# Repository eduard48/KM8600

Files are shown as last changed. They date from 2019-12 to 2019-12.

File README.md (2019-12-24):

# Конфигурируемый контроллер серии КМ тип КМ8600 

>КМ8600 – контроллер для жестких условий эксплуатации

>>Выпускается [здесь](http://www.sem-act.ru)

>>Тип модуля: КM01-8600.M

>>Версия: 0330

В папке Firmware проект для AtmelStudio v.6.2

В папке Hardware две платы (контроллер и модуль индикации) для Altium Desinger 2017.

В папке Docs описания и документы.

				>Краткие характеристики

>>Дискретных входов - 8

>>Дискретных выходов - 6 (реле с NO контактами)

>>Номинальное напряжение питания - 24 VDC

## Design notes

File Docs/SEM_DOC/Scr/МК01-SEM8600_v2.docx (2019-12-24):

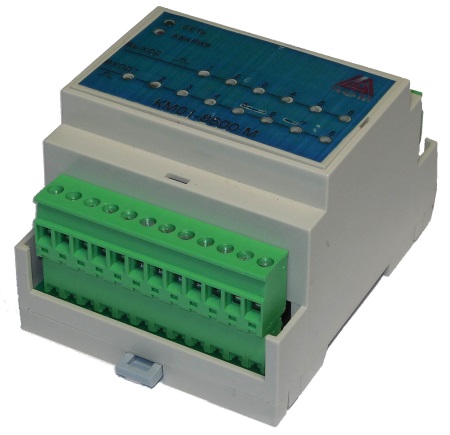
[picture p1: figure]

КМ – серия контроллеров для жестких условий эксплуатации Модуль: КM01-8600.M

Основные технические характеристики:

Напряжение питания 24VDC +/-20%

Рабочая температура -40…+70С

Потребляемая мощность 2.4Вт

Защита цепей 6 видов

Программа конфигуратор, единая на всю серию модулей КМ, поставляется бесплатно

Кол-во дискретных входных сигналов 8

Кол-во дискретных выходных сигналов 6

Гальванически развязанный интерфейс RS485

Поддержка протокола ModBus RTU

Габаритные размеры 85х71х57мм

Установка на DIN-рейку

Гальванически развязанные входы могут быть сконфигурированы как счетные (8 входов).

Выходы с открытым коллектором могут быть сконфигурированы как выходы ШИМ (2 выхода).

Релейные выходы могут коммутировать ток до 5 Ампер.

Защита по питанию и питанию входов - само-восстанавливающимися предохранителями.

Поставляются совместно с библиотекой функций для программирования на языке С.

Используется совместно со Scada системами такими как: Vijeo Citect, Citect, Master Scada и т.д.

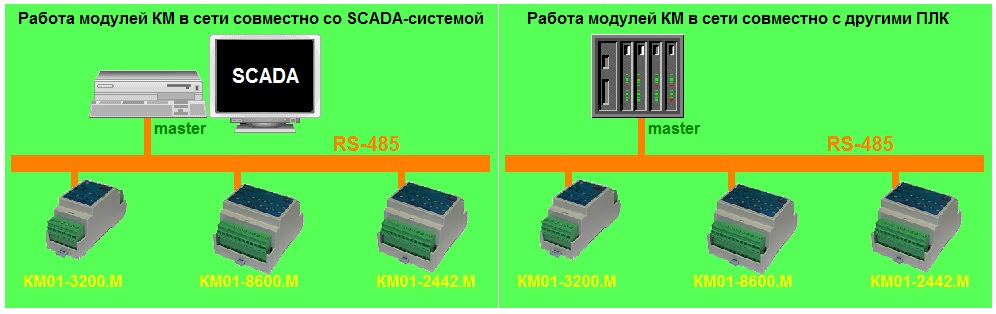
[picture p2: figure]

Более подробные характеристики смотреть в инструкции по эксплуатации модуля КМ01-8600.М

Настройки конфигурации смотреть в инструкции пользователя программой “Конфигуратор КМ”

Программирование смотреть в “Инструкция по программированию контроллера КМ01-8600.М”

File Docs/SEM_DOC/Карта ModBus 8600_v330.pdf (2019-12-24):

## KM01-8600.M (версия ПО 330)

Регистры Input | (регистры только для чтения)
ModBus addr | Имя регистра | Описание | Примечание | Тип памяти
30001 | MB_Ireg[0] | Слово жизни контроллера | Постоянное изменение - контроллер работает | RAM
30002 | MB_Ireg[1].0 | Состояние входа DI1
30002 | MB_Ireg[1].1 | Состояние входа DI2
30002 | MB_Ireg[1].2 | Состояние входа DI3
30002 | MB_Ireg[1].3 | Состояние входа DI4
30002 | MB_Ireg[1].4 | Состояние входа DI5
30002 | MB_Ireg[1].5 | Состояние входа DI6
30002 | MB_Ireg[1].6 | Состояние входа DI7
30002 | MB_Ireg[1].7 | Состояние входа DI8
30002 | MB_Ireg[1].8 | Состояние входа контроля напряжения UDI
30002 | MB_Ireg[1].9 | Резерв
30002 | MB_Ireg[1].10 | Резерв
30002 | MB_Ireg[1].11 | Резерв
30002 | MB_Ireg[1].12 | Резерв
30002 | MB_Ireg[1].13 | Резерв
30002 | MB_Ireg[1].14 | Резерв
30002 | MB_Ireg[1].15 | Резерв
30002 | MB_Ireg[1] | Состояние дискретных входов DI | 8 входов + 1 контроль напряжения питания входов | RAM
30003 | MB_Ireg[2].0 | Состояние выхода DO1
30003 | MB_Ireg[2].1 | Состояние выхода DO2
30003 | MB_Ireg[2].2 | Состояние выхода DO3
30003 | MB_Ireg[2].3 | Состояние выхода DO4
30003 | MB_Ireg[2].4 | Состояние выхода DO5
30003 | MB_Ireg[2].5 | Состояние выхода DO6
30003 | MB_Ireg[2].6 | Резерв
30003 | MB_Ireg[2].7 | Резерв
30003 | MB_Ireg[2].8 | Резерв
30003 | MB_Ireg[2].9 | Резерв
30003 | MB_Ireg[2].10 | Резерв
30003 | MB_Ireg[2].11 | Резерв
30003 | MB_Ireg[2].12 | Резерв
30003 | MB_Ireg[2].13 | Резерв
30003 | MB_Ireg[2].14 | Резерв
30003 | MB_Ireg[2].15 | Резерв
30003 | MB_Ireg[2] | Состояние дискретных выходов DO | 6 выходов (4 реле и 2 с ОК) | RAM
30004 | MB_Ireg[3] | Резерв
30005 | MB_Ireg[4] | Резерв
30006 | MB_Ireg[5] | Резерв
30007 | MB_Ireg[6] | Резерв
30008 | MB_Ireg[7] | Резерв
30009 | MB_Ireg[8] | Резерв
30010 | MB_Ireg[9] | значение дискретного выхода №5 | Если задана работа в качестве ШИМ, дипазон 0…255
30011 | MB_Ireg[10] | значение дискретного выхода №6 | Если задана работа в качестве ШИМ, дипазон 0…255
30004…30011 | MB_Ireg[3]…[10] | Значения аналоговых входов/выходов | | RAM
30012 | MB_Ireg[11] | Старшее число текущего значения для счетного входа №1
30013 | MB_Ireg[12] | Младшее число текущего значения для счетного входа №1
30014 | MB_Ireg[13] | Старшее число текущего значения для счетного входа №2
30015 | MB_Ireg[14] | Младшее число текущего значения для счетного входа №2
30016 | MB_Ireg[15] | Старшее число текущего значения для счетного входа №3
30017 | MB_Ireg[16] | Младшее число текущего значения для счетного входа №3
30018 | MB_Ireg[17] | Старшее число текущего значения для счетного входа №4
30019 | MB_Ireg[18] | Младшее число текущего значения для счетного входа №4
30020 | MB_Ireg[19] | Старшее число текущего значения для счетного входа №5
30021 | MB_Ireg[20] | Младшее число текущего значения для счетного входа №5
30022 | MB_Ireg[21] | Старшее число текущего значения для счетного входа №6
30023 | MB_Ireg[22] | Младшее число текущего значения для счетного входа №6
30024 | MB_Ireg[23] | Старшее число текущего значения для счетного входа №7
30025 | MB_Ireg[24] | Младшее число текущего значения для счетного входа №7
30026 | MB_Ireg[25] | Старшее число текущего значения для счетного входа №8
30027 | MB_Ireg[26] | Младшее число текущего значения для счетного входа №8
30012…30027 | MB_Ireg[11]…[26] | Значения счетных входов | | RAM
30028 | MB_Ireg[27].0 | Состояние инд. дискретного Выхода №6 | зеленый светодиод №6
30028 | MB_Ireg[27].1 | Состояние инд. дискретного Выхода №5 | зеленый светодиод №5
30028 | MB_Ireg[27].2 | Состояние инд. дискретного Выхода №4 | зеленый светодиод №4
30028 | MB_Ireg[27].3 | Состояние инд. дискретного Выхода №3 | зеленый светодиод №3
30028 | MB_Ireg[27].4 | Состояние инд. дискретного Выхода №2 | зеленый светодиод №2
30028 | MB_Ireg[27].5 | Состояние инд. дискретного Выхода №1 | зеленый светодиод №1
30028 | MB_Ireg[27].6 | Состояние инд. "Неисправность" | Красный светодиод
30028 | MB_Ireg[27].7 | резерв
30028 | MB_Ireg[27].8 | Состояние инд. дискретного Входа №8 | желтый светодиод №8
30028 | MB_Ireg[27].9 | Состояние инд. дискретного Входа №7 | желтый светодиод №7
30028 | MB_Ireg[27].10 | Состояние инд. дискретного Входа №6 | желтый светодиод №6
30028 | MB_Ireg[27].11 | Состояние инд. дискретного Входа №5 | желтый светодиод №5
30028 | MB_Ireg[27].12 | Состояние инд. дискретного Входа №4 | желтый светодиод №4
30028 | MB_Ireg[27].13 | Состояние инд. дискретного Входа №3 | желтый светодиод №3
30028 | MB_Ireg[27].14 | Состояние инд. дискретного Входа №2 | желтый светодиод №2
30028 | MB_Ireg[27].15 | Состояние инд. дискретного Входа №1 | желтый светодиод №1
30028 | MB_Ireg[27] | Состояние индикации (светодиодов) | Используется для сдвигового регистра индикации | RAM
30029 | MB_Ireg[28] | KM
30030 | MB_Ireg[29] | 01
30031 | MB_Ireg[30] | -8
30032 | MB_Ireg[31] | 60
30033 | MB_Ireg[32] | 0.
30034 | MB_Ireg[33] | M0
30035 | MB_Ireg[34] | резерв
30036 | MB_Ireg[35] | резерв
30029...30036 | MB_Ireg[28]…[35] | Имя модуля в памяти | Пример: KM01-8600.M (длинна макс 16 символов) | RAM
30037 | MB_Ireg[36] | 02 | 02 - версия загрузчика
30038 | MB_Ireg[37] | 03 | 03
30039 | MB_Ireg[38] | 00 | 00
30037...30039 | MB_Ireg[36]…[38] | Номер версии ПО | Пример: 020300 | RAM
30040 | MB_Ireg[39] | 09 | 09 - неделя выпуска
30041 | MB_Ireg[40] | 00
30042 | MB_Ireg[41] | 01
30040…30042 | MB_Ireg[39]…[41] | Серийный номер контроллера | Пример: серийный номер 090001 | RAM
Регистры Hold | (регистры для чтения и записи)

ModBus addr | Имя регистра | Описание | Примечание | Тип памяти
40001 | MB_Hreg[0] | Резерв | Это все
40002 | MB_Hreg[1] | Резерв | для
40003 | MB_Hreg[2] | Резерв | пользовательской программы
40004 | MB_Hreg[3] | Резерв | Если надо!
40005 | MB_Hreg[4] | Резерв
40001…40005 | MB_Hreg[0]…[4] | Резерв | | RAM
40006 | MB_Hreg[5].0 | Управление выходом DO1
40006 | MB_Hreg[5].1 | Управление выходом DO2
40006 | MB_Hreg[5].2 | Управление выходом DO3
40006 | MB_Hreg[5].3 | Управление выходом DO4
40006 | MB_Hreg[5].4 | Управление выходом DO5
40006 | MB_Hreg[5].5 | Управление выходом DO6
40006 | MB_Hreg[5].6 | Резерв
40006 | MB_Hreg[5].7 | Резерв
40006 | MB_Hreg[5].8 | Резерв
40006 | MB_Hreg[5].9 | Резерв
40006 | MB_Hreg[5].10 | Резерв
40006 | MB_Hreg[5].11 | Резерв
40006 | MB_Hreg[5].12 | Резерв
40006 | MB_Hreg[5].13 | Резерв
40006 | MB_Hreg[5].14 | Резерв
40006 | MB_Hreg[5].15 | Резерв
40006 | MB_Hreg[5] | Слово состояния и управления дискретными выходами контроллера | | RAM
40007 | MB_Hreg[6] | резерв
40008 | MB_Hreg[7] | резерв
40009 | MB_Hreg[8] | Управление выходом ШИМ DO5 | Имеет значение только если выход настроен на работу в качестве ШИМ. Изменяется только (0…255)
40010 | MB_Hreg[9] | Управление выходом ШИМ DO6 | Имеет значение только если выход настроен на работу в качестве ШИМ. Изменяется только (0…255)
40007…40010 | MB_Hreg[6]…[9] | Слова управления аналоговыми выходами | | RAM
40011 | MB_Hreg[10] | резерв
40012 | MB_Hreg[11] | резерв
40013 | MB_Hreg[12] | резерв
40014 | MB_Hreg[13] | резерв
40015 | MB_Hreg[14] | резерв
40016 | MB_Hreg[15] | резерв
40017 | MB_Hreg[16] | резерв
40018 | MB_Hreg[17] | резерв
40019 | MB_Hreg[18] | резерв
40020 | MB_Hreg[19] | резерв
40021 | MB_Hreg[20] | резерв
40022 | MB_Hreg[21] | резерв
40023 | MB_Hreg[22] | резерв
40024 | MB_Hreg[23] | резерв
40025 | MB_Hreg[24] | резерв
40026 | MB_Hreg[25] | резерв
40027 | MB_Hreg[26] | резерв
40028 | MB_Hreg[27] | резерв
40029 | MB_Hreg[28] | резерв
40030 | MB_Hreg[29] | резерв
40031 | MB_Hreg[30] | резерв
40032 | MB_Hreg[31] | резерв
40033 | MB_Hreg[32] | резерв
40034 | MB_Hreg[33] | резерв
40011…40034 | MB_Hreg[10]…[33] | Резерв | | RAM
40035 | MB_Hreg[34].0 | Режим ШИМ для выхода №5 (DO5) включен
40035 | MB_Hreg[34].1 | Режим ШИМ для выхода №6 (DO6) включен
40035 | MB_Hreg[34].2 | Резерв
40035 | MB_Hreg[34].3 | Резерв
40035 | MB_Hreg[34].4 | Резерв
40035 | MB_Hreg[34].5 | Резерв
40035 | MB_Hreg[34].6 | Резерв
40035 | MB_Hreg[34].7 | Резерв
40035 | MB_Hreg[34].8…9 | Задание частоты ШИМ для выходов №5, №6 | 00 - 60Гц, 01-120Гц, 10-240Гц, 11-580Гц
40035 | MB_Hreg[34].10 | Резерв
40035 | MB_Hreg[34].11 | Резерв
40035 | MB_Hreg[34].12 | Резерв
40035 | MB_Hreg[34].13 | Резерв
40035 | MB_Hreg[34].14 | Резерв
40035 | MB_Hreg[34] | Параметры ШИМ для выходов с ОК (№5, №6) | Новые параметры работают только перезагрузки. | RAM, EEPROM
40036 | MB_Hreg[35].0 | Вход №1 работает как счетный
40036 | MB_Hreg[35].1 | Вход №2 работает как счетный
40036 | MB_Hreg[35].2 | Вход №3 работает как счетный
40036 | MB_Hreg[35].3 | Вход №4 работает как счетный
40036 | MB_Hreg[35].4 | Вход №5 работает как счетный
40036 | MB_Hreg[35].5 | Вход №6 работает как счетный
40036 | MB_Hreg[35].6 | Вход №7 работает как счетный
40036 | MB_Hreg[35].7 | Вход №8 работает как счетный
40036 | MB_Hreg[35].8
40036 | MB_Hreg[35].9
40036 | MB_Hreg[35].10
40036 | MB_Hreg[35].11
40036 | MB_Hreg[35].12
40036 | MB_Hreg[35].13
40036 | MB_Hreg[35].14
40036 | MB_Hreg[35].15
40036 | MB_Hreg[35] | Режим работы цифровых входов | Новые параметры работают только перезагрузки. | RAM, EEPROM
40037 | MB_Hreg[36] | Число накопителя для счетного входа №1
40038 | MB_Hreg[37] | Число накопителя для счетного входа №2
40039 | MB_Hreg[38] | Число накопителя для счетного входа №3
40040 | MB_Hreg[39] | Число накопителя для счетного входа №4
40041 | MB_Hreg[40] | Число накопителя для счетного входа №5
40042 | MB_Hreg[41] | Число накопителя для счетного входа №6
40043 | MB_Hreg[42] | Число накопителя для счетного входа №7
40044 | MB_Hreg[43] | Число накопителя для счетного входа №8
40045 | MB_Hreg[44] | Старшее число начального значения для счетного входа №1
40046 | MB_Hreg[45] | Младшее число начального значения для счетного входа №1
40047 | MB_Hreg[46] | Старшее число начального значения для счетного входа №2

40048 | MB_Hreg[47] | Младшее число начального значения для счетного входа №2
40049 | MB_Hreg[48] | Старшее число начального значения для счетного входа №3
40050 | MB_Hreg[49] | Младшее число начального значения для счетного входа №3
40051 | MB_Hreg[50] | Старшее число начального значения для счетного входа №4
40052 | MB_Hreg[51] | Младшее число начального значения для счетного входа №4
40053 | MB_Hreg[52] | Старшее число начального значения для счетного входа №5
40054 | MB_Hreg[53] | Младшее число начального значения для счетного входа №5
40055 | MB_Hreg[54] | Старшее число начального значения для счетного входа №6
40056 | MB_Hreg[55] | Младшее число начального значения для счетного входа №6
40057 | MB_Hreg[56] | Старшее число начального значения для счетного входа №7
40058 | MB_Hreg[57] | Младшее число начального значения для счетного входа №7
40059 | MB_Hreg[58] | Старшее число начального значения для счетного входа №8
40060 | MB_Hreg[59] | Младшее число начального значения для счетного входа №8
40061 | MB_Hreg[60] | резерв
40037…40061 | MB_Hreg[36]…[60] | Уставки для счетных входов | Новые параметры работают только перезагрузки. | RAM, EEPROM
40062 | MB_Hreg[61].0…7 | Адрес контроллера в сети ModBus | Сетевой адрес
40062 | MB_Hreg[61].8 | резерв
40062 | MB_Hreg[61].9 | резерв
40062 | MB_Hreg[61].10 | резерв
40062 | MB_Hreg[61].11 | резерв
40062 | MB_Hreg[61].12 | резерв
40062 | MB_Hreg[61].13 | резерв
40062 | MB_Hreg[61].14 | резерв
40062 | MB_Hreg[61].15 | резерв
40062 | MB_Hreg[61] | Параметры сети MODBUS | Новые параметры работают только перезагрузки. | RAM, EEPROM
40063 | MB_Hreg[62].0…7 | Категория скорости в сети | 0x00, 0x01, 0x02, 0x06 - 9600 бит/сек
40063 | | | 0x03 - 1200 бит/сек
40063 | | | 0x04 - 2400 бит/сек
40063 | | | 0x05 - 4800 бит/сек
40063 | | | 0x07 - 19200 бит/сек
40063 | | | 0x08 - 38400 бит/сек
40063 | | | 0x09 - 57600 бит/сек
40063 | | | 0x0A - 115200 бит/сек
40063 | MB_Hreg[62].8…15 | Параметры обмена | default | 0x00 - 8, Even, 1
40063 | | | 0x01 - 8, Even, 2
40063 | | | 0x02 - 8, None, 1
40063 | | | 0x03 - 8, None, 2
40063 | MB_Hreg[62] | Параметры RS - 485 | Новые параметры работают только перезагрузки. | RAM, EEPROM
40064 | MB_Hreg[63].0 | Выполнить перезагрузку | Работает только при записи в этот бит 1. Т.е. по фронту сигнала.
40064 | MB_Hreg[63] | Команды контроллера | Срабатывает при изменении 0 бита на 1 | RAM

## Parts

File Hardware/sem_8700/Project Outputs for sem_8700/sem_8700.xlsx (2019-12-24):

Comment | Designator | Footprint | Quantity
0.1 | C1, C3, C6, C8, C9, C10, C11, C12, C15, C16 | CAPC2113X13N_0805 | 10
470.0x50V | C2 | Cap_pol_13x25 | 1
470 pF | C4 | CAPC2113X13N_0805 | 1
470.0x35V | C5 | Cap_2(10x12.5) | 1
22.0x16V | C7 | Cap_4(5x10) | 1
22p | C13, C14 | CAPC2113X13N_0805 | 2
47.0x35V | C17 | Cap_4(5x10) | 1
BAT54S_1 | D1, D2, D3, D4, D5, D6, D7, D8, D10 | BAT54S_1 | 9
SMDJ36CA | D9, D12 | SMB_1 | 2
SM4007 | D11 | DIOD_SM1 | 1
SS18 | D13 | DIOD_SMA | 1
ESDA6V1L | D14 | SOT23_diod_ESDA | 1
500mA | F1, F2 | Fuse_termo | 2
MC34063 | IC1 | SOIC_SO-8 | 1
ISP | ISP | ISP_1 | 1
Conn_12x1 | J1, J2 | conn12_2 | 2
jamper | JP1, JP11 | JP_2_2.5 | 2
220mH | L2 | Dr_1 | 1
TLP281GB | OP1, OP2, OP3, OP4, OP5, OP6, OP7, OP8, OP9 | SOIC127_TPL | 9
TRJ | P1, P2, P3, P4 | PCB_rele_TRJ | 4
TMA_0505 | PW2 | TMA_1W | 1
4k7 | R1, R3, R5, R7, R9, R11, R13, R15, R17 | RES_1206 | 9
4k7 | R2, R4, R6, R8, R10, R12, R14, R16, R18, R24, R25 | RESC2113X0805N | 11
1 Om | R19 | RES_1206 | 1
1k2 | R20 | RESC2113X0805N | 1
3k6 | R21 | RESC2113X0805N | 1
470 Om | R22 | RES_1206 | 1
10k | R23 | RESC2113X0805N | 1
10 Om | R26, R27 | RESC2113X0805N | 2
120 Om | R28 | RES_1206 | 1
47k | R29 | RESC2113X0805N | 1
ATmega164PA-AU | U1 | 44A_N | 1
ULN2003A | UC1 | PDIP16_1 | 1
ADUM1301 | UC2 | SOIC127P1030X265-16N_SOIC_W | 1
ADM1485 | UC3 | SOIC127P600X175-8N_SOIC_SO8 | 1
CN1206K25G | VR1, VR2, VR3, VR4, VR5, VR6, VR7, VR8 | var1206 | 8
XP6x1 | XP1 | Connect6_1 | 1
7.3728 | ZQ1 | ZQ_1 | 1

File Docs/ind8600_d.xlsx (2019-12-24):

Comment | Designator | Value | Footprint | Quantity
0.1 | C1, C2 | 0.1mF | 0805 | 2
74HC595 | IC1, IC2 |  | SOIC_16 | 2
Red | LD1 |  | светодиод 3мм красный | 1
Green | LD2, LD3, LD4, LD5, LD6, LD7, LD20 |  | светодиод 3мм зеленый | 7
Yell | LD8, LD9, LD10, LD11, LD12, LD13, LD14, LD15 |  | светодиод 3мм желтый | 8
1k | R1, R2, R3, R4, R5, R6, R7, R8, R9, R10, R11, R12, R13, R14, R15, R20 | 1k | 0805 | 16
XP6x1 | XP1 |  | штыри 6_1 | 1

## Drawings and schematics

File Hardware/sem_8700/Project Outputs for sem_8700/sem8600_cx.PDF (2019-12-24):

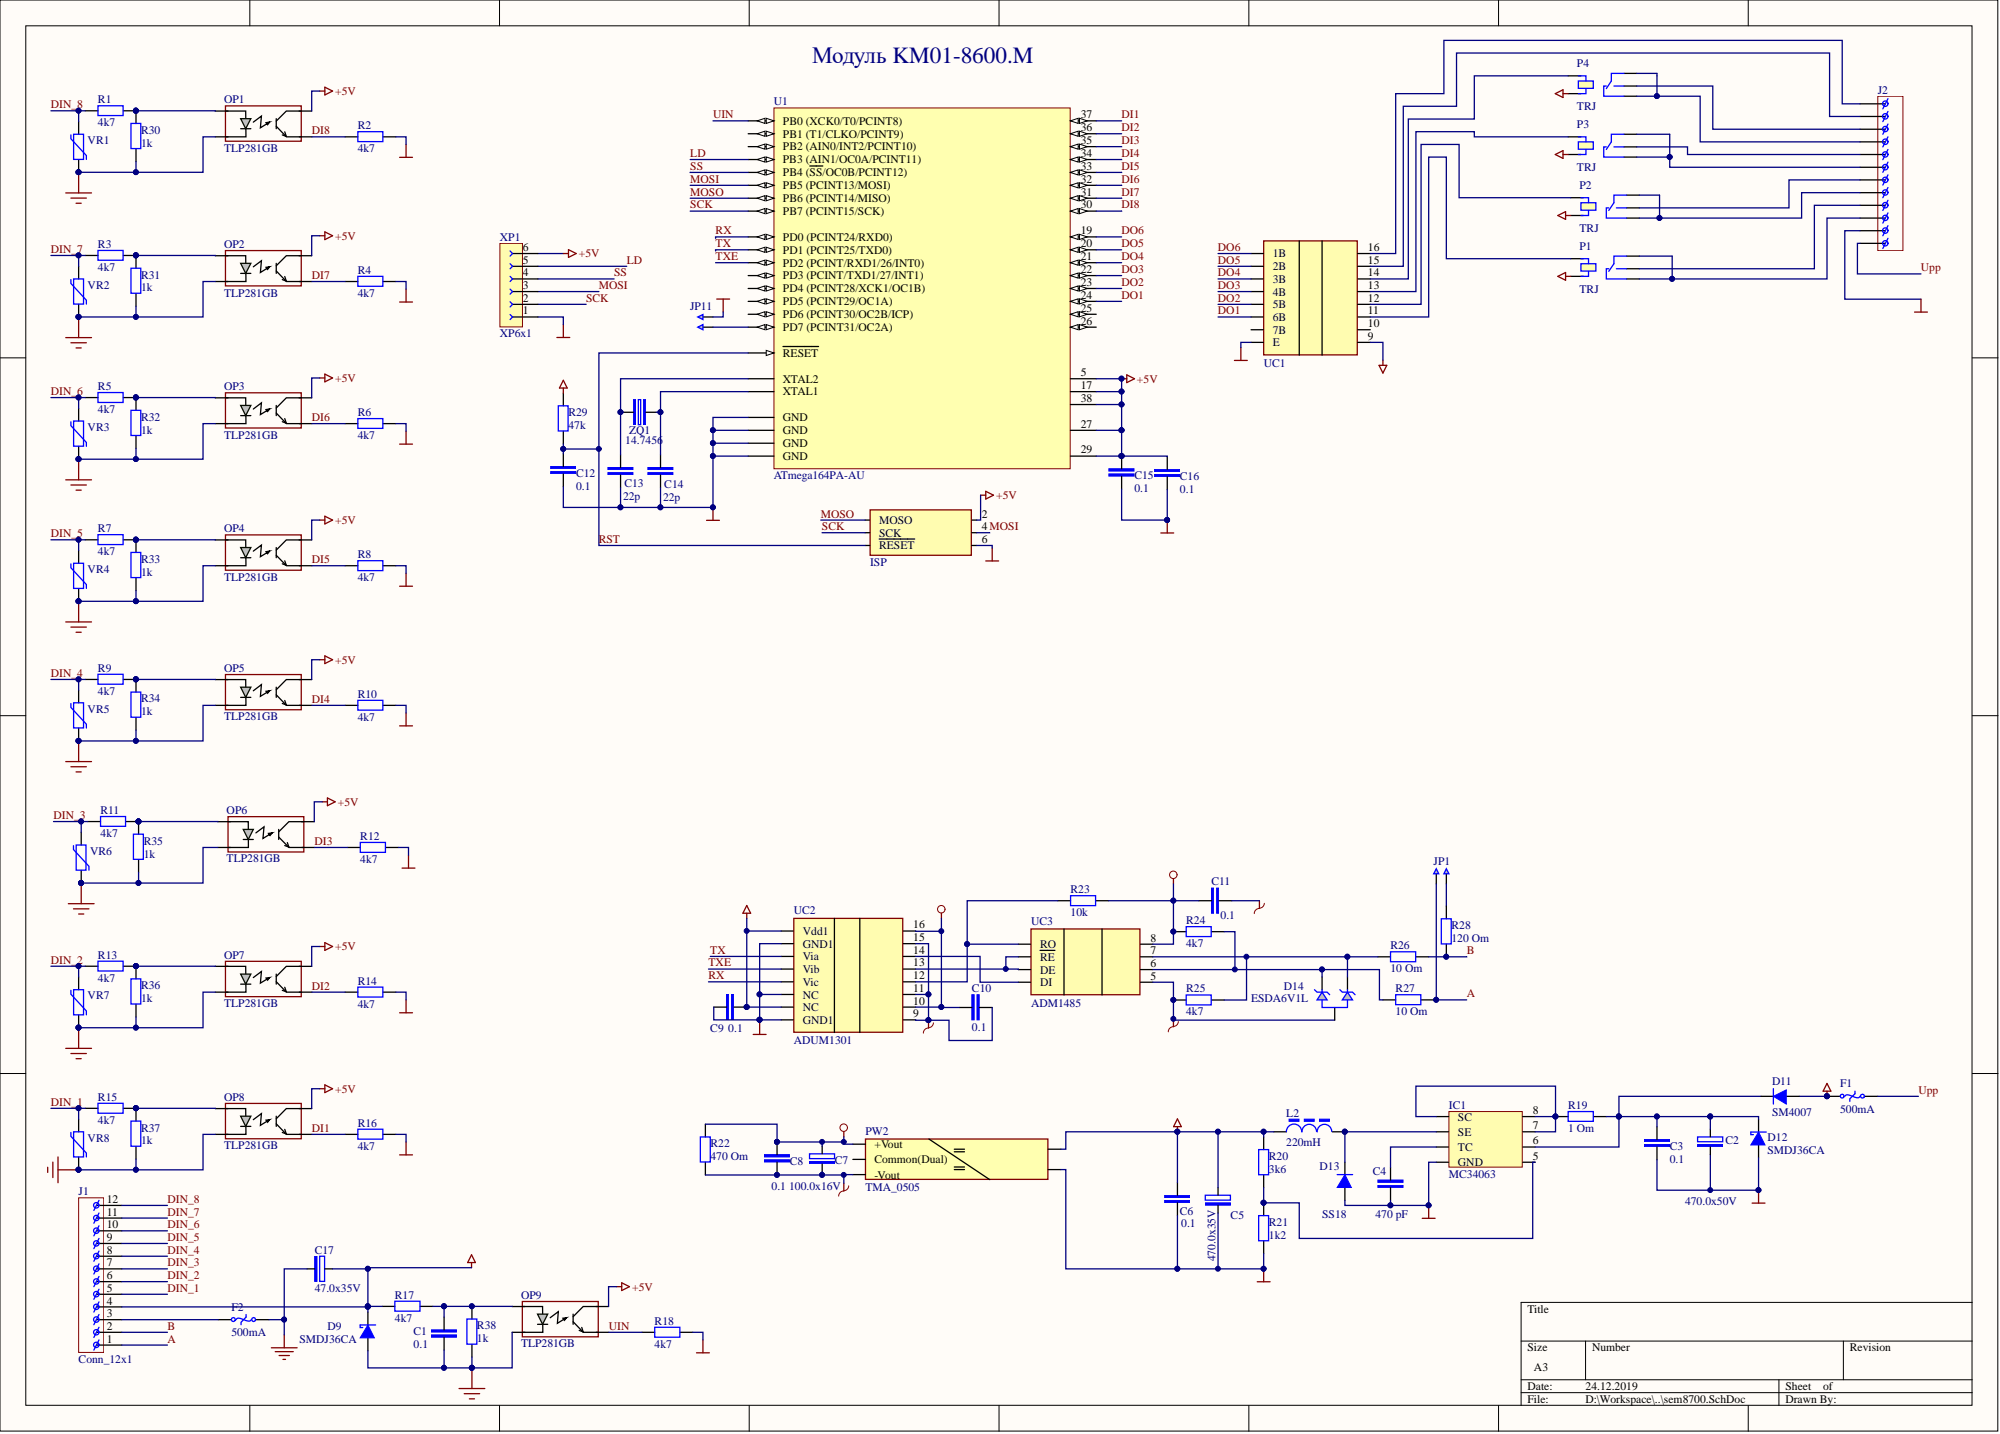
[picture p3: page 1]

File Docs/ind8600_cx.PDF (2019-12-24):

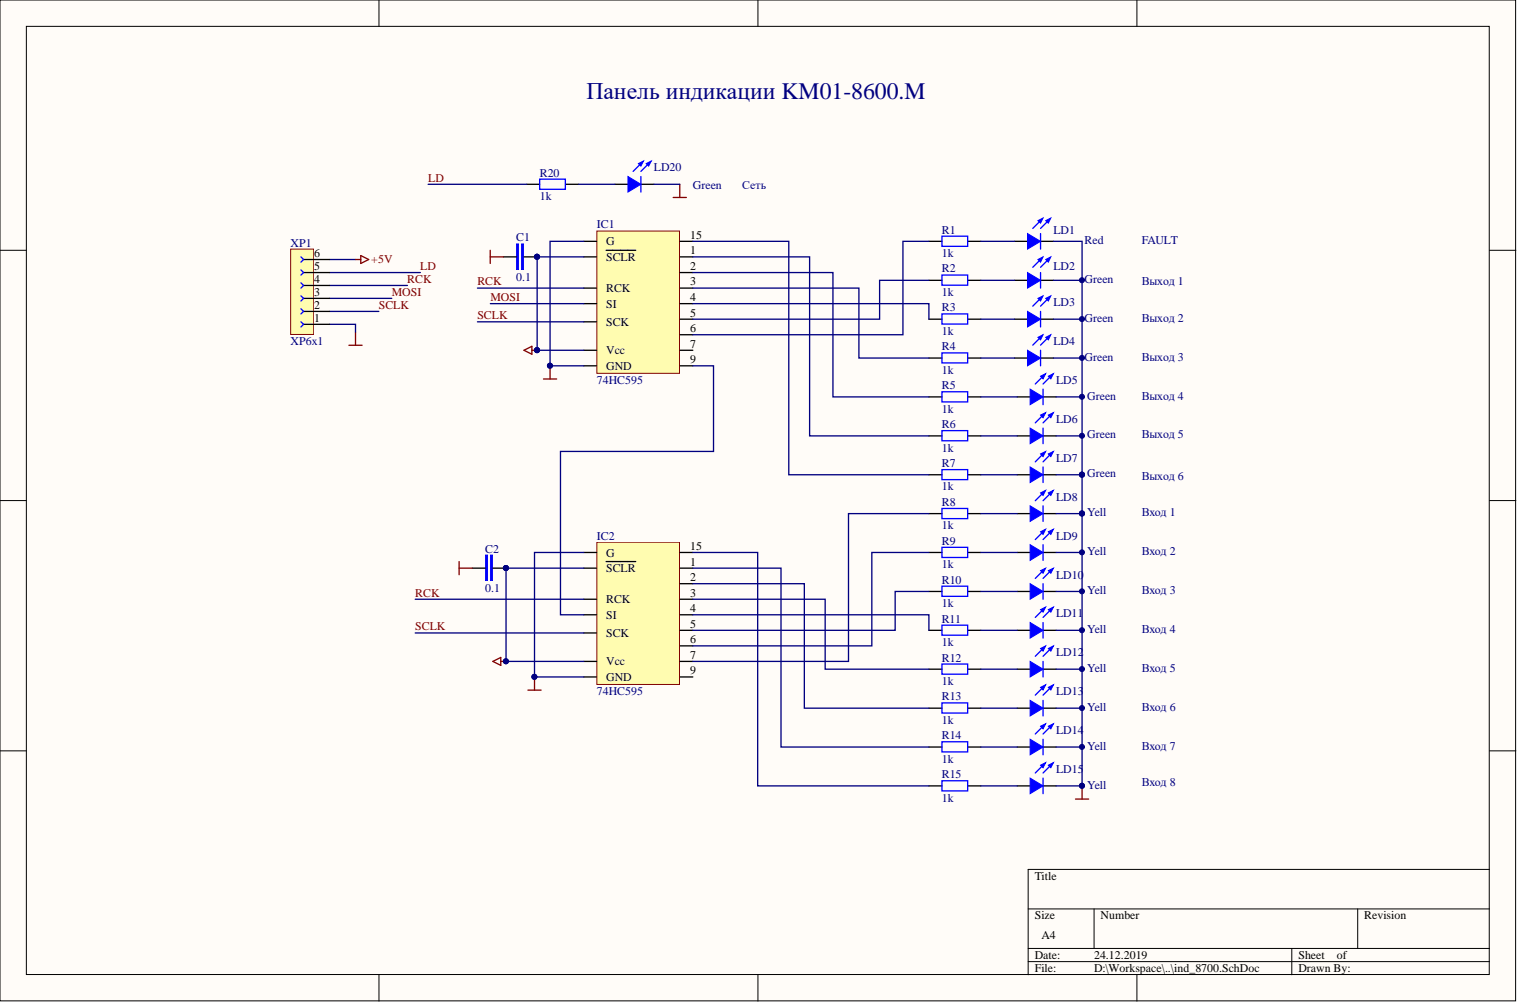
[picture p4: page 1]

LD1 Red
FAULT Вход 1 Вход 2 Вход 3

3 | | | | LD3
4 | 1k R3
6 | | LD4

1 | | LD10
4 | 1k R1 1 | LD1 1
6 | 1k R12 | LD12

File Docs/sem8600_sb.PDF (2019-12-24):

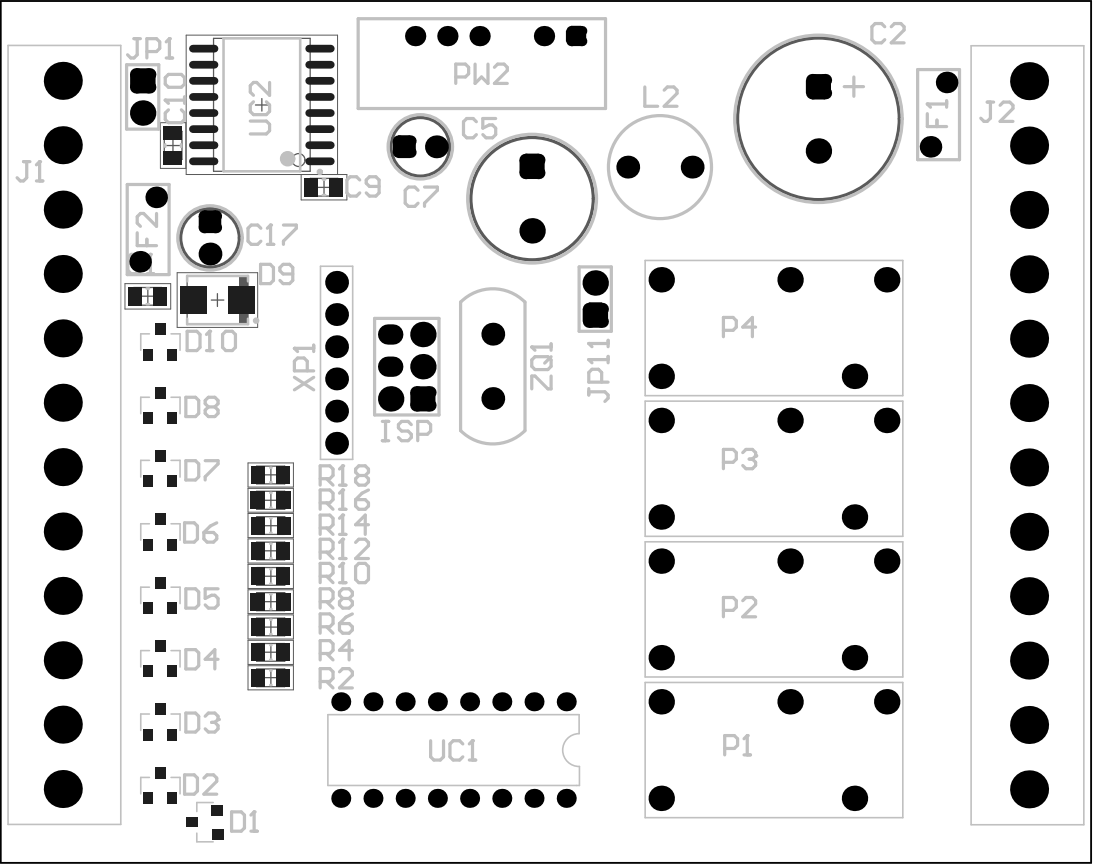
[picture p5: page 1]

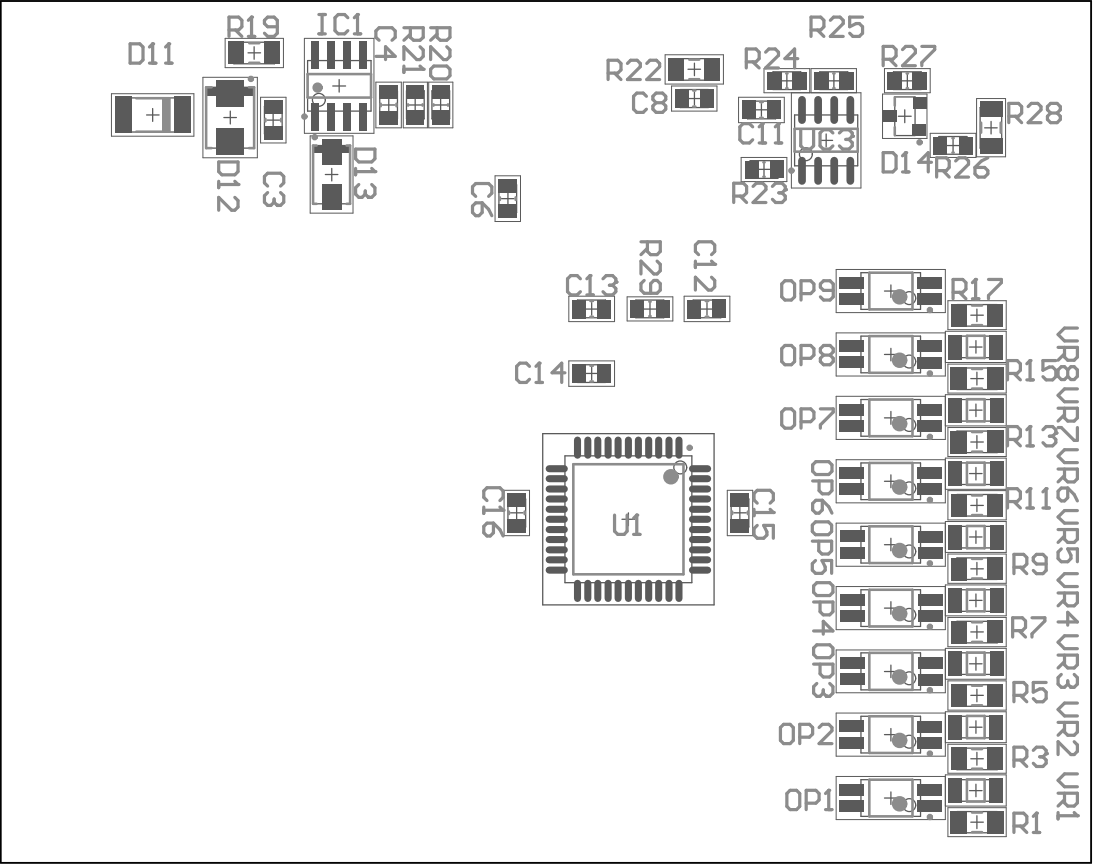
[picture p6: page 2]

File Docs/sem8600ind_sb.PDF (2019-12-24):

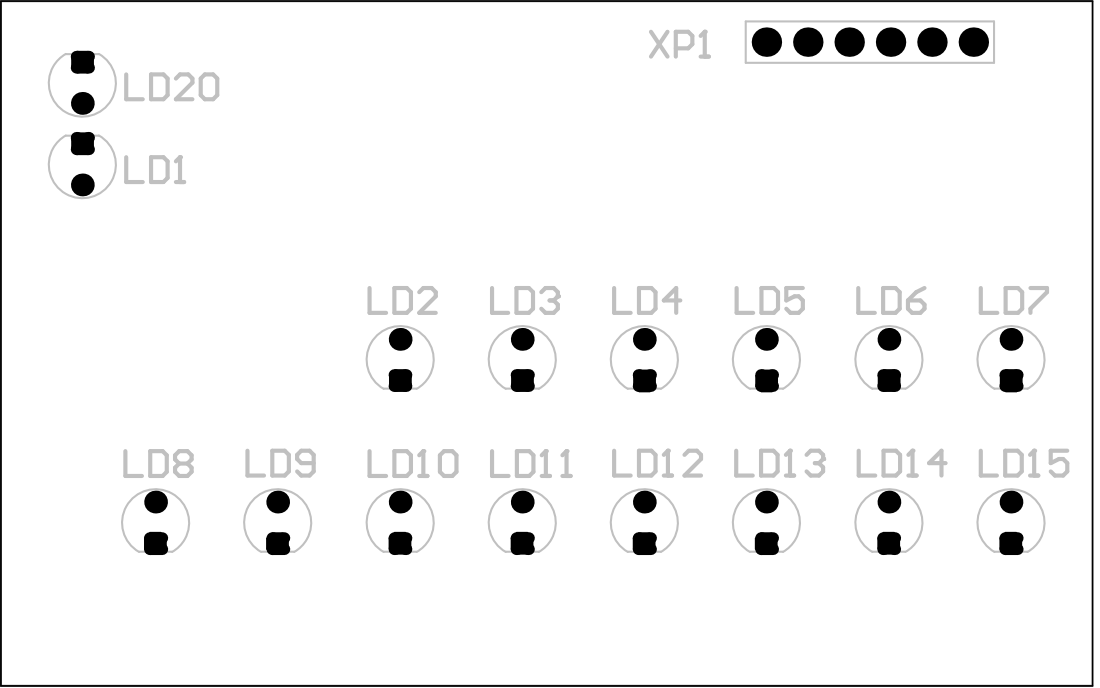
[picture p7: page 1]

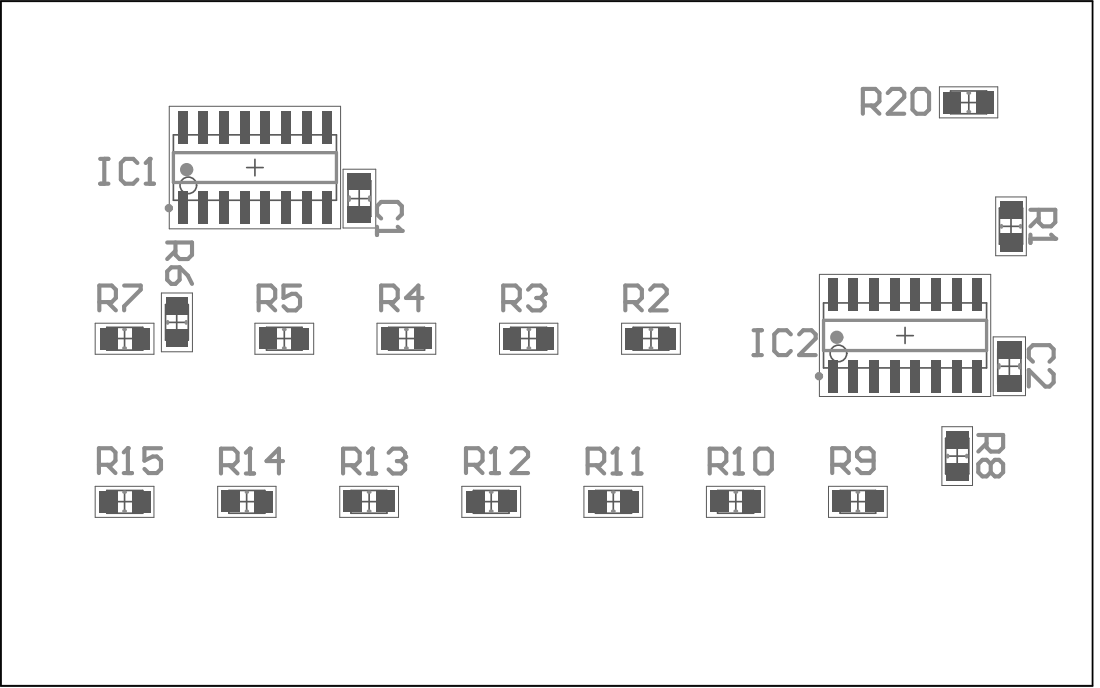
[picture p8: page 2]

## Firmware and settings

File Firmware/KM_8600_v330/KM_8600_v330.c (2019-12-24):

/********************************************************************************************************************************
 * KM_8600_v330.c
 *
 * Created: 11.07.2015 15:42:51
 *  Author: Ed
 * version: 3.30
 *
 * Программа для KM01-8600.M0
 * Программа никакой полезной функциональности не несет и сделана как шаблон для дальнейшего наполнения полезной функциональности
 * Смотреть описание карты регистров!
 ********************************************************************************************************************************/ 
/* Используемые выводы контроллера ATMEGA324PA
* PA0 - input IN1
* PA1 - input IN2
* PA2 - input IN3
* PA3 - input IN4
* PA4 - input IN5
* PA5 - input IN6
* PA6 - input IN7
* PA7 - input IN8
*
* PB0 - input UIN (Контроль напряжения питания цифровых входов)
* PB1 - NC
* PB2 - NC
* PB3 - output LD (выход управления зеленым светодиодом ПИТАНИЕ на панели индикации)
* PB4 - output SS(SPI) (выход управления выводом информации загруженой в регистры сдвига на панели индикации)
* PB5 - output MOSI(SPI) (выход последовательной загрузки данных в сдвиговые регистры панели индикации)
* PB6 - input MOSO(SPI) (вход для программирования контроллера по интерфейсу SPI)
* PB7 - output SCK(SPI) (выход синхронизации для обмена по SPI)
*
* PC0 - output DO6 (ОК)
* PC1 - output DO5 (ОК)
* PC2 - output DO4 (реле)
* PC3 - output DO3 (реле)
* PC4 - output DO2 (реле)
* PC5 - output DO1 (реле)
* PC6 - NC
* PC7 - NC
*
* PD0 - input RX(UART) (вход RX для работы по UART (подтянут к +))
* PD1 - output TX(UART) (выход TX для работы по UART)
* PD2 - output TXE(RS485) (выход для управления направления обмена по RS485)
* PD3 - NC
* PD4 - NC
* PD5 - NC
* PD6 - NC
* PD7 - input JP (вход подтянут к +, используется для активизации bootloader)
***********************************************************************************************************************************
* Внесенные изменения: 16.03.2014
* исправил регистры счетных входов, увеличил кол-во регистров Input и Hold для резерва. теперь можно считывать до 124 регистров.
* исправил индикацию флагов в регистре состояния выходов. 
* Новые не задействованные регистры Input и Hold можно использовать в программе пользователя!!!
* Внесенные изменения: 11.07.2015 Переделан принцип работы, убран файл task, задачи выполняются непосредственно по таймеру1
* Ответы на запросы модбас отсылаются из основной программы. 13.07.2015 (проверено).
**********************************************************************************************************************************/
// --- Основные объявления ---
// размер буфера макс = 255!!!
#define F_CPU 14745600UL 			
#define COM_RX_BUFFER_SIZE 255		
#define COM_TX_BUFFER_SIZE 255		

// --- Включаемые стандартные библиотеки ---
#include <avr/io.h>
#include <avr/eeprom.h>
#include <avr/pgmspace.h>

// --- Включаемые sem библиотеки ---
#include "km_8600.h"
#include "net.h"
#include "ioport.h"
#include "mem.h"

void user_main(void);		// объявление пользовательской функции
void work_sys(void);		// объявление для использования в любом месте программы

//------------------- Сообщение компилятора (для информации) -----------------------
#ifdef	_KM8600_
#warning "MESSAGE - Select type device - KM01-8600.M ver.0330"
#endif
//================== Работа с собачьм таймером ======================================
/* На будущее
void InitWdt(void)
{
	MCUSR &= ~(1<<WDRF); 			// д.б. сброшен (если = 1, то и WDE = 1 !!!)
	asm("wdr");						// сброс счетчика WDT
	WDTCSR |= (1<<WDE)|(1<<WDCE);	// для сброса WDE - надо делать так!
	WDTCSR = 0x0F;					// 2 сек и разрешен сброс по тайм ауту
}
*/
// ============ takt_timer выполняется по прерыванию каждые 10 мсек =================
void takt_timer(void)
{  unsigned char n;
	n = TimerTakt;
	if (n) TimerTakt = --n;		// Время выполнения основного цикла
	n = TimerLed;
	if (n) TimerLed = --n;		// Уменьшить счетчик
}
// ============ Обработка прерывания таймера 1 (каждые 10 мсек) =====================
ISR(TIMER1_OVF_vect)
{
	TCNT1H = 0xFF;
	TCNT1L = 255 - 144;
	takt_timer();
}
//=========================== Функция инициализации ядра ============================
void Init(void)
{
unsigned char i;

	_delay_ms(500);		// Задержка при старте
	InitLine();			// Настраиваю порты контроллера
//	InitWdt();			// Настройка сторожевого таймера (пока в резерве
	LD_on;				// Включить зеленый светодиод
	WDR();				// Сброс собачьего таймера
	_delay_ms(500);		// Задержка при старте
	for(i=0; i<maxAddrRegINP;i++) { MB_Ireg[i] = 0; }	// Очистить INPUT регистры
	for(i=0; i<maxAddrRegHOLD; i++) { MB_Hreg[i] = 0; }	// Очистить HOLD регистры
	_delay_ms(100);		// Задержка
	WDR();				// Сброс собачьего таймера
	if((PIND & 0x80) == 0) 
		{ 
			set_default(); 
			for(i=0; i<5; i++) // Моргнуть 5 раз!
			{
			LD_off; 
			_delay_ms(100); 
			LD_on; 
			_delay_ms(100); 
			}
		}
	WDR();						// Сброс собачьего таймера
	InitMem();					// Заполняю регистры Модбас данными из памяти
	CNT_clear();				// Очистить счетные регистры
	WDR();						// Сброс собачьего таймера
	InitDev();					// Инициализация внутренних систем контроллера
	LD_off;						// Выключить зеленый светодиод
	MB_Ireg[27] = 0x0000;		// выкл все
	LED_Update();				// Обновить
	WDR();						// Сброс собачьего таймера
	_delay_ms(1000);			// Тест светодиодов (проверка работоспособности)
	MB_Ireg[27] = 0xFF00;		// вкл входы
	LED_Update();				// Обновить
	WDR();						// Сброс собачьего таймера
	_delay_ms(500);				// Тест светодиодов (проверка работоспособности)
	MB_Ireg[27] = 0x003F;		// Вкл выходы
	LED_Update();				// Обновить
	WDR();						// Сброс собачьего таймера
	_delay_ms(500);				// Тест светодиодов (проверка работоспособности)
	MB_Ireg[27] = 0x0040;		// Включить красный
	LED_Update();				// Обновить
	WDR();						// Сброс собачьего таймера
	_delay_ms(500);				// Тест светодиодов (проверка работоспособности)
	MB_Ireg[27] = 0x0000;		// выкл все
	LED_Update();				// Обновить
	LD_on;						// Включить зеленый светодиод
	WDR();						// Сброс собачьего таймера
	_delay_ms(500);				// Тест светодиодов (проверка работоспособности)
	WDR();						// Сброс собачьего таймера
	INP_Read();					// Считываю текущие состояния входов
	COM_Init((char) MB_Hreg[62],(char) (MB_Hreg[62] >> 8)); // Настраиваю UART0 для работы RS-485
	Address_device = (char) MB_Hreg[61];					// Переписываю адрес контроллера в сети ModBus
	// ----- Настраиваю работу таймера №1 ----
	TCCR1B = (1 << CS12)|(1<< CS10);	// Timer1 / 1024 - делим тактовую на 1024
	TCNT1H = 0xFF;
	TCNT1L = 255 - (F_CPU / 1024 / 100);	// Прерывания каждые 10мсек!
	TIMSK1 |= (1<<TOIE1);					// Включить прерывания Timer 1 при переполнении
}

// =========================== Команда перезагрузки контроллера ====================================================
void command_reboot(void)
{
//if((MB_Hreg[63] &0x01) != 0) {cli(); while(1);} // Перезагрузка по сбросу собачьего таймера (пока в резерве)
if((MB_Hreg[63] &0x01) != 0) {_delay_ms(20); asm("rjmp restart;");} // Если есть 1 то перейти на метку перезагрузки
}
//============================ Работа ядра системы =================================================================
int main(void)
{
	// --- Инициализация ---
	cli();
	_delay_ms(500);	// Задержка при старте
asm("restart:");	// Метка для перехода по команде перезагрузки
	Init();			// Инициализация системы...
	sei();			// Разрешить глобальные прерывания	
	TimerTakt = 10; // Задачу выполнять каждые 100мсек
	TimerLed = 0;	// Светодиод включен!
	while(1)
	{
		WDR(); // Сброс собачьего таймера
		if(Read_Modbus() == 1)	{TimerLed = 10; MODBUS_RTU();}	// Если пакет принят, обработать принятый пакет ModBus
		if(TimerLed) LD_off; else LD_on; // выключить светодиод на 100мсек - принят пакет с адресом модуля
		if(TimerTakt == 0)
		{
			TimerTakt = 10; // Перезагрузка таймера - следующее выполнение программы через 10*10=100мсек
			// --- Состояния входов в рег Input меняются по прерываниям ---
			OUT_Read();			// Чтение состояния выходов
			IND_Update();		// Обновить состояние индикации
			//******************Здесь м.б. программа пользователя***********************************
			
			//**************************************************************************************
			OUT_Update();		// Обновить состояние дискретных выходов
			rd_cnt();			// Обновить показания счетчиков
			command_reboot();	// Проверить команду - не пора ли перезагрузиться???
			// === Формирую слово жизни контроллера ===
			if(MB_Ireg[0] <= 0xFFFA) MB_Ireg[0]++;
			else MB_Ireg[0] = 0;
		}
	}
}

//***************************************************************************** END ************************************************************************************

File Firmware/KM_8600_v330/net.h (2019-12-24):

/*****************************************************************************************************************
* Здесь для приема пакета ModBus использую прерывания таймера0.
******************************************************************************************************************/
#ifndef _NET_										//Защита от повторного включения файла
#define _NET_

#include <avr/io.h>								//Стандартная библиотека ввода/вывода
#include <avr/interrupt.h>						//Библиотека обработки прерываний
#include <util/delay.h>							//Стандартная библиотека временных задержек

#ifndef F_CPU
# warning "F_CPU not defined. Frequency by default 14.7456MHz"
#define F_CPU 14745600UL							/*Стандартная константа задающая частоту микроконтроллера (необходима для корректной работы функций задержек)*/
#endif

#include "ioport.h"
#include "mem.h"

#ifndef COM_RX_BUFFER_SIZE
# warning "COM_RX_BUFFER_SIZE not defined. Value will be set by default 64 bytes"
#define COM_RX_BUFFER_SIZE 64						/*Длина приемного буфера*/
#endif
#ifndef COM_TX_BUFFER_SIZE
# warning "COM_TX_BUFFER_SIZE not defined. Value will be set by default 64 bytes"
#define COM_TX_BUFFER_SIZE 64						/*Длина передающего буфера*/
#endif


//---------------------------- Работа с сетью RS485 ---------------------------
// --------------------- Для контроллера типа КМ01-8600.М ---------------------
#define NET_DDR               DDRD
#define NET_PIN               PIND
#define NET_PORT              PORTD
#define NET_RX                0x00
#define NET_TX                0x01
#define NET_TXE               0x02

#define NET_UBRRH             UBRR0H
#define NET_UBRRL             UBRR0L
#define NET_UCSRA             UCSR0A
#define NET_UCSRB             UCSR0B
#define NET_UCSRC             UCSR0C
#define NET_UDR               UDR0

//---------------------------- Работа с протоколом ModBus ---------------------
char _Frame_pause;								//Флаг превышения интервала 1.5 символа в Modbus RTU (1-интервал превышен/0-превышения не было)
//unsigned char _Net_tFrame;						// определяет заданную длинну паузы между приемом байт
//unsigned char _NET_tPause;						// счетчик длинны пауз

char _UART_RX_Buf[COM_RX_BUFFER_SIZE];	//Приемный буфер UART
char _UART_RX_dup[COM_RX_BUFFER_SIZE];	//Копия приемного буфера UART
int _UART_RX_point;						//Текущая позиция в приемном буфере UART
char _UART_RX_length;					//Длина принятой посылки по UART
char _UART_RX_end;						//Признак окончания принятой посылки по UART

char _UART_TX_Buf[COM_TX_BUFFER_SIZE];	//Передающий буфер UART
int _UART_TX_point;						//Текущая позиция в передающем буфере UART
char _UART_TX_length;					//Длинна отправляемой посылки по UART
char _UART_TX_end;						//Признак окончания передачи по UART

// ********************** Определю используемые внутренние переменные для протокола MODBUS RTU *********************************
unsigned char m_coderr;	// Содержит код ошибки
char Func;				//Код функции (Func) Содержит выполняемую команду
int SubFunc;			//Код подфункции (SubFunc) Начальный адрес регистрового поля из запроса
int Data;				//Регистр данных (Data) Кол-во запрашиваемых квантов (регистров или выводов)

//-------------------------------------
void MODBUS_RTU(void);

//------------------------------------------------------------------------------------------
//======================== Прерывание по совпадению А таймера 0 ============================
// === пакет принят ===
//------------------------------------------------------------------------------------------
SIGNAL(TIMER0_COMPA_vect)
{
	int temp;														//Вспомогательная переменная
	
	_Frame_pause=0;													//Обнуление флага превышения интервала 1.5 символа
	for (temp=0; temp<_UART_RX_point; temp++) _UART_RX_dup[temp]=_UART_RX_Buf[temp];//Копирование приемного буфера
	_UART_RX_length=_UART_RX_point;								    //Вычисление длины принятой посылки
	_UART_RX_point=0;										        //Указатель приемного буфера на начало
	TCCR0A=0x00;													//Остановка таймера
	TCCR0B=0x00;													//Остановка таймера
	_UART_RX_end=1;
//	LD_on;										// вкл светодиод
}

//------------------------------------------------------------------------------------------
//======================== Прерывание по совпадению B таймера 0 ============================
//------------------------------------------------------------------------------------------
SIGNAL(TIMER0_COMPB_vect)
{
	_Frame_pause=1;														//Установить флаг превышения интервала 1.5 символа
}

//================================== Функция расчета контрольной суммы в протоколе Modbus RTU ====================================
//Функция принимает:
//*buf-указатель на массив в котором содержатся данные для расчета контрольной суммы
//Len-количество байт участвующих в расчете контрольной суммы
int _CRC_calc(char *buf, char Len)
{
	unsigned int CRC;														//Переменная для расчета контрольной суммы
	char temp,temp2;														//Вспомогательные переменные
	
	CRC=0xFFFF;																//Начальное значение CRC (по алгоритму расчета CRC)
	for (temp=0; temp<Len; temp++)											//Цикл для всех байт участвующих в расчете
	{
		CRC=CRC^*buf;														//"Исключающее или" (по алгоритму расчета CRC)
		buf++;																//Указатель на следующий байт
		for (temp2=0; temp2<8; temp2++)										//Цикл для каждого бита в байте
		if ((CRC & 0x0001)==0) CRC=CRC>>1;									//Если младший бит в единице, просто сдвиг (по алгоритму расчета CRC)
		else
		{
			CRC=CRC>>1;														//Сдвиг	и "Исключающее или" (по алгоритму расчета CRC)
			CRC=CRC^0xA001;													//Полином для "Исключающего или" 1010 0000 0000 0001
		}
	}
	
	return CRC;																//Возврат расчитанной контрольной суммы
}
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
